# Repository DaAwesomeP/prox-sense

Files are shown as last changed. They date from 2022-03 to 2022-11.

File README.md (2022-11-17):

prox-sense
==========

[prox-sense](https://github.com/DaAwesomeP/prox-sense) is a series of printed
circuit board (PCB) designs for designed to bring robust and discreet
capacitive proximity and touch sensing to artists and makers.

**Video demonstration and poster: [Hidden Touch: Open Source Sensors for New
Interaction](https://perrynaseck.com/work/prox-sense/)**

This repository contains the KiCAD schematics, boards, and Gerber files
required to produce the sensing boards. License notice below.

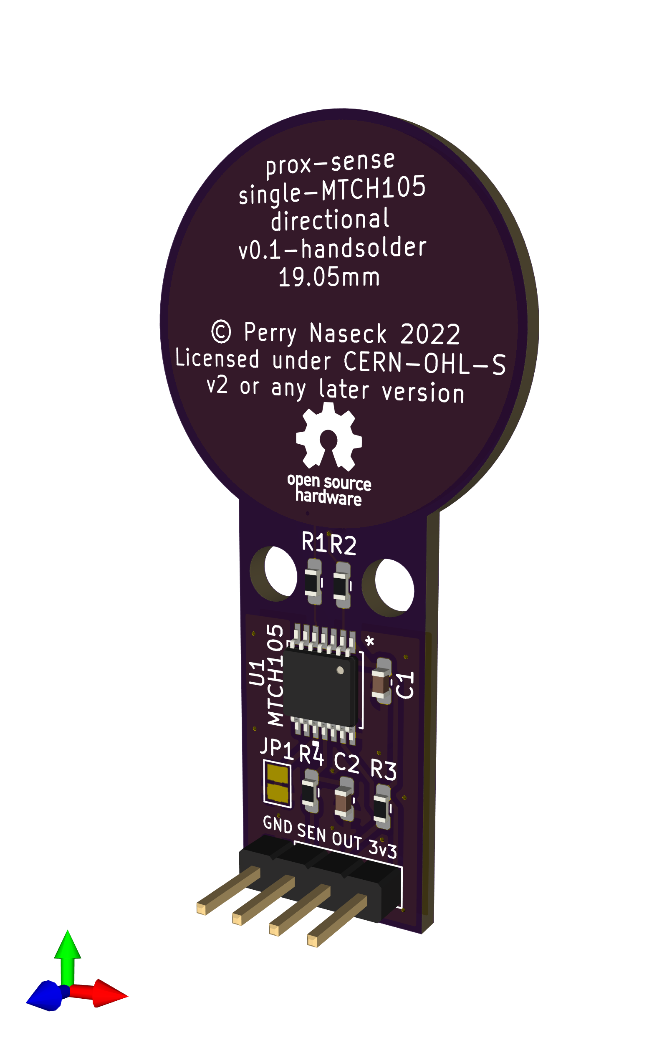
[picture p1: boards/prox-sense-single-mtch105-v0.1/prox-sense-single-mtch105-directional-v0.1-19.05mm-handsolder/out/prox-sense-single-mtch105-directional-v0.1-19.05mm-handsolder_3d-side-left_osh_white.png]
prox-sense directional board


## Premise

**Existing systems for creating interactive experiences:**

 - Expensive
 - Can be difficult to use or understand
 - Limited or nonexistent proximity detection (existing capacitive options)
 - Dense arrangements of proximity sensors may not function (existing
   capacitive options)
 - Connectivity options do not scale up to large systems of sensors
 - Equivalent/alternative optical systems are intrusive, expensive, or
   predictable (cameras, vision systems)
 - Require large amounts of processing or setup
 - Existing tactile systems are predictable (buttons, knobs, touchscreens,
   etc.)

**prox-sense promotes discoverable and new interactions:**

 - Inexpensive
 - Focus on proximity detection
 - Proximity through solid and opaque objects (sensors can be entirely hidden)
 - Directional proximity detection options allow for dense arrangements
 - Interaction is led by the objects the sensors are hidden in and the
   resulting interactions, not the sensors and sensor limitations
 - Small sensors allow for small detection areas and objects
 - Simple connectivity scales up to large systems without limiting the maximum
   number of easily-connected sensors
 - Open source and free to produce

## Boards

Currently all boards are based around the [Microchip
MTCH105](https://www.microchip.com/en-us/product/MTCH105)

 - Simple GPIO interface for detection and sensitivity adjustment. The standard
   logic output can be used directly with microcontrollers, logic circuits,
   transistors, muxes, and port expanders
 - Rejects liquids and other uncertain signal sources
 - Supports guard reference signal for solid interference mitigation
 - All boards currently use the same schematic but vary the copper/trace layout
   to achieve different detection patterns

### Directional board

 - Detects proximity and touch only directly in front of the sensors
 - Rejects rear and off-axis (side) detection using guard signal
 - Guard signal on edge allows for close-packing of sensors

### Omnidirectional board

 - Detects proximity and touch from all directions
 - Guard signal on edge allows for close-packing of sensors

## License Notice
Copyright Perry Naseck 2022.

This source describes Open Hardware and is licensed under the CERN-OHL-S v2.

You may redistribute and modify this source and make products using it under
the terms of the CERN-OHL-S v2 (https://ohwr.org/cern_ohl_s_v2.txt).

This source is distributed WITHOUT ANY EXPRESS OR IMPLIED WARRANTY,
INCLUDING OF MERCHANTABILITY, SATISFACTORY QUALITY AND FITNESS FOR A
PARTICULAR PURPOSE. Please see the CERN-OHL-S v2 for applicable conditions.

Source location: https://github.com/DaAwesomeP/prox-sense

As per CERN-OHL-S v2 section 4, should You produce hardware based on this
source, You must where practicable maintain the Source Location visible
on the external case of the prox-sense or other products you make using this
source.

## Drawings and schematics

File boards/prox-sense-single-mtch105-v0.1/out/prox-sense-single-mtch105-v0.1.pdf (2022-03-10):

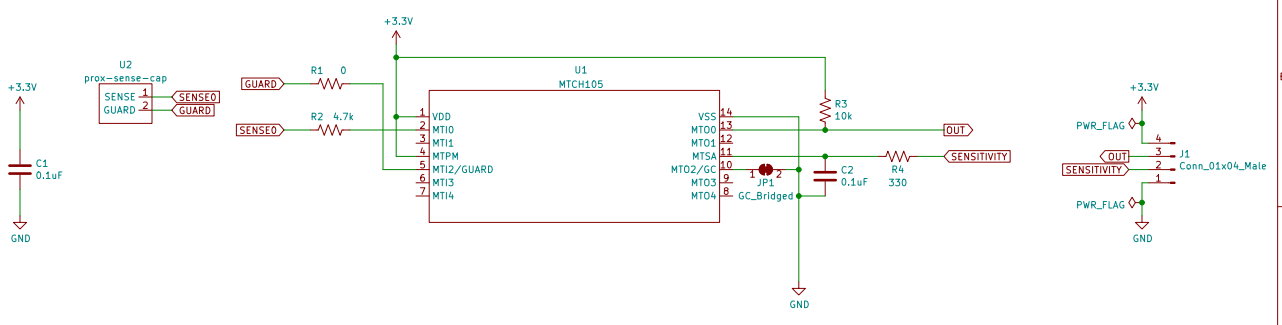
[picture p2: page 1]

Copyright Perry Naseck 2022; licensed under CERN-OHL-S v2 or any later version PWR_FLAG

MTCH105 used in place of MTCH102 due to chip shortage
This schematic used for multiple board layouts
File: prox-sense-single-mtch105-v0.1.kicad_sch Sheet: / Perry Naseck

Id: 1/1 Title: Prox Sense Single MTCH105

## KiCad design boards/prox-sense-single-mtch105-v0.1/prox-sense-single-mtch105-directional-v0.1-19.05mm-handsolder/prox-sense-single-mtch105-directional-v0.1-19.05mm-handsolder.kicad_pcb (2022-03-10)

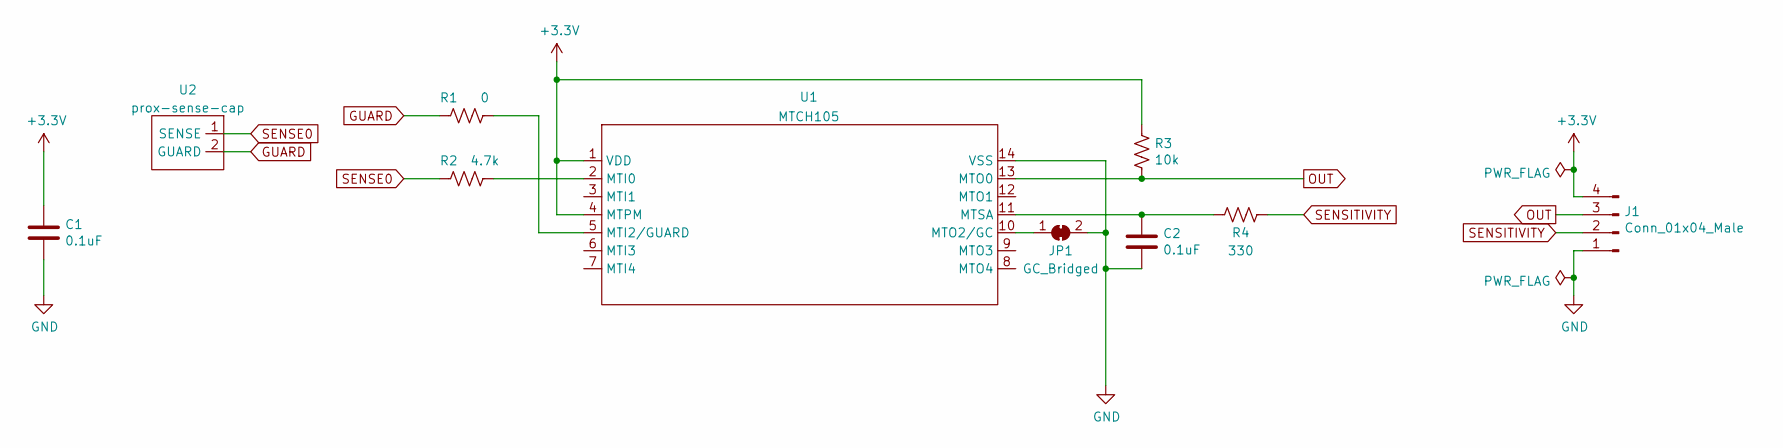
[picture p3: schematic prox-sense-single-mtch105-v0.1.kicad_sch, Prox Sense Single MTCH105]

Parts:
C1, C2: 0.1uF; C_0603_1608Metric_Pad1.08x0.95mm_HandSolder
J1: Conn_01x04_Male; PinHeader_1x04_P2.54mm_Vertical
JP1: GC_Bridged; SolderJumper-2_P1.3mm_Bridged_Pad1.0x1.5mm
R1: 0; R_0603_1608Metric_Pad0.98x0.95mm_HandSolder
R2: 4.7k; R_0603_1608Metric_Pad0.98x0.95mm_HandSolder
R3: 10k; R_0603_1608Metric_Pad0.98x0.95mm_HandSolder
R4: 330; R_0603_1608Metric_Pad0.98x0.95mm_HandSolder
U1: MTCH105; MTCH105-I&slash_ST
U2: prox-sense-cap; prox-sense-cap-omni-19.05mm

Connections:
+3V3: C1.1, J1.4, R3.1, U1.1 (VDD), U1.4 (MTPM)
GND: C1.2, C2.2, J1.1, JP1.2 (B), U1.14 (VSS)
GUARD: R1.2, U2.2 (GUARD)
unnamed: C2.1, R4.2, U1.11 (MTSA)
unnamed: JP1.1 (A), U1.10 (MTO2/GC)
unnamed: R1.1, U1.5 (MTI2/GUARD)
unnamed: R2.1, U1.2 (MTI0)
OUT: J1.3, R3.2, U1.13 (MTO0)
SENSE0: R2.2, U2.1 (SENSE)
SENSITIVITY: J1.2, R4.1

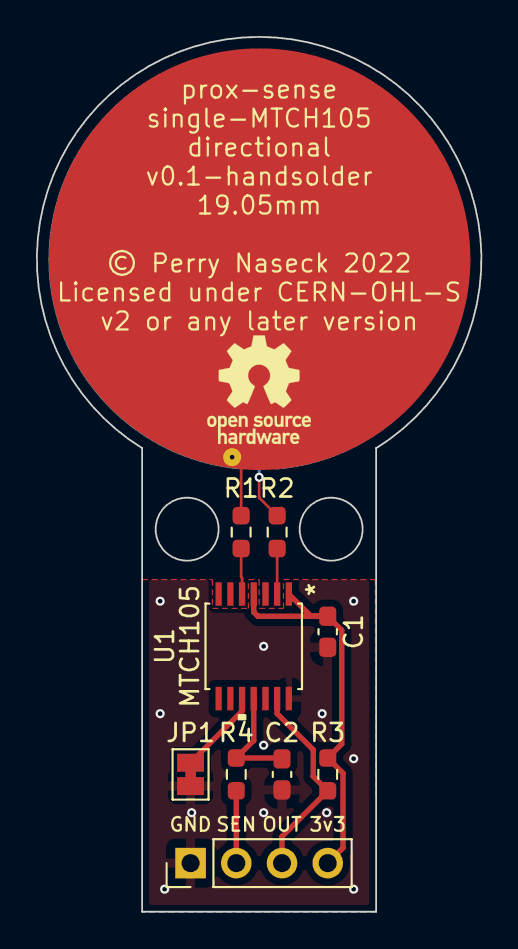
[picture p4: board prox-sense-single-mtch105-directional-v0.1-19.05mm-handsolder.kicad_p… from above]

Board: 2 copper layers, 24.7 x 48.6 mm, 10 parts (1 on the bottom side), 10 nets.

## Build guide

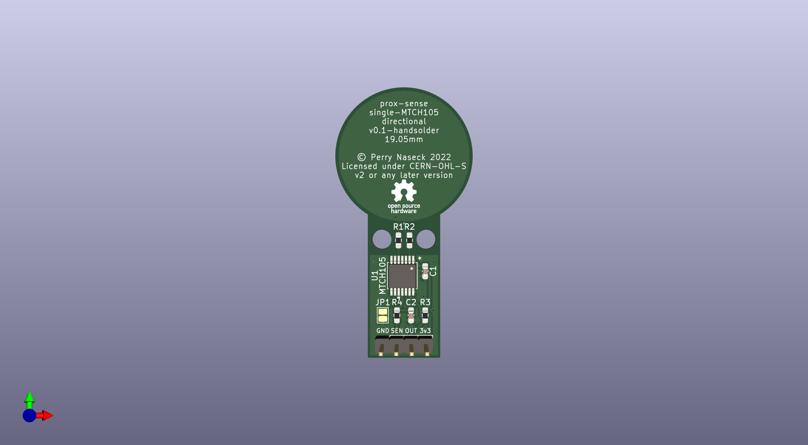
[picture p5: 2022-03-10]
boards/prox-sense-single-mtch105-v0.1/prox-sense-single-mtch105-directional-v0.1-19.05mm-handsolder/out/prox-sense-single-mtch105-directional-v0.1-19.05mm-handsolder_3d-front.png

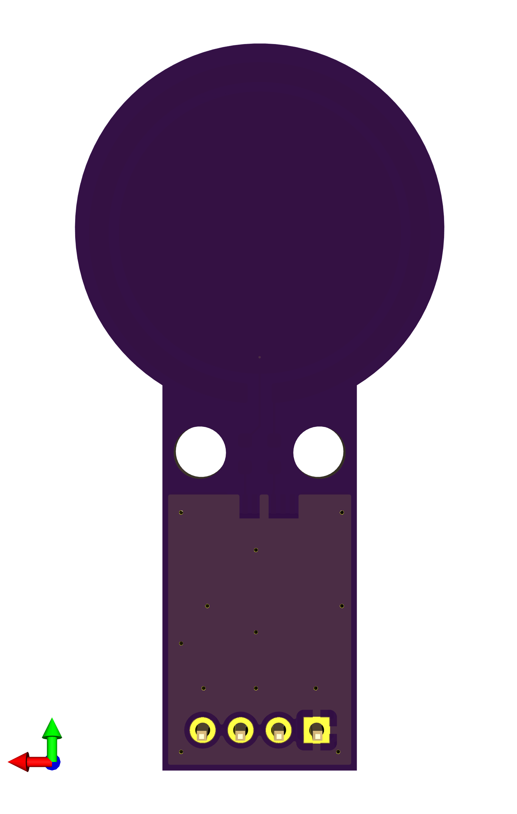
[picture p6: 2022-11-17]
boards/prox-sense-single-mtch105-v0.1/prox-sense-single-mtch105-omni-v0.1-19.05mm-handsolder/out/prox-sense-single-mtch105-omni-v0.1-19.05mm-handsolder_3d-rear_osh_white.png

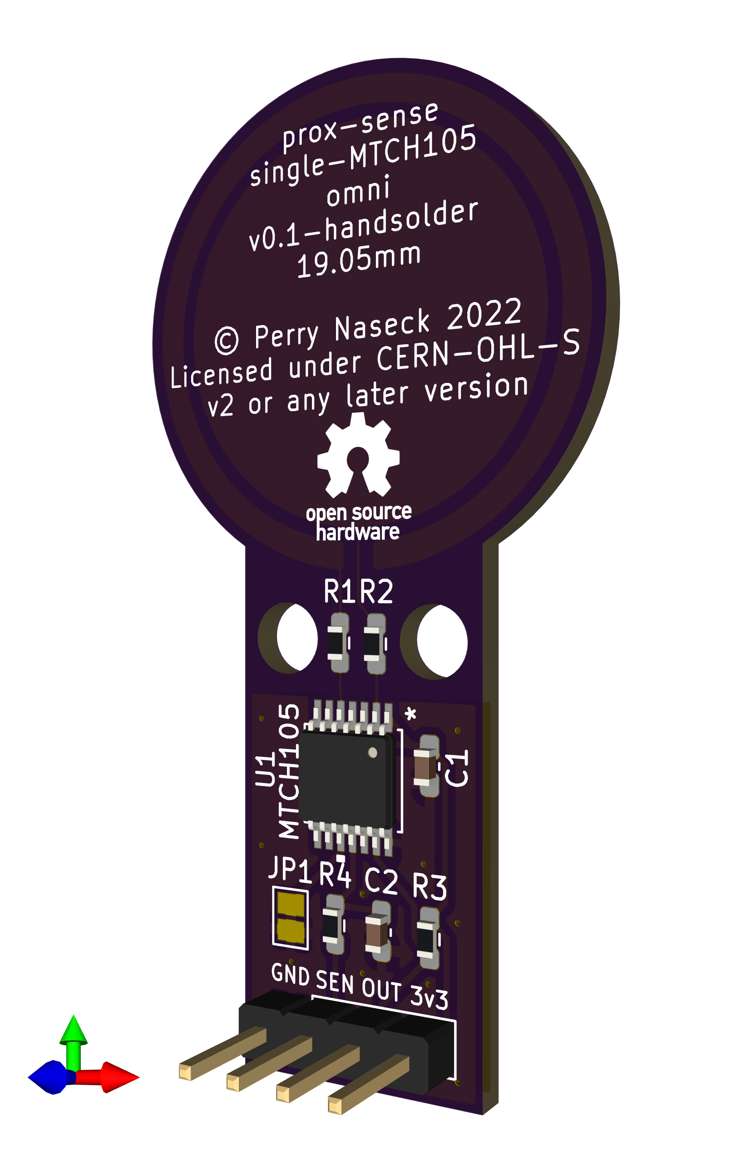
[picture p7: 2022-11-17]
boards/prox-sense-single-mtch105-v0.1/prox-sense-single-mtch105-omni-v0.1-19.05mm-handsolder/out/prox-sense-single-mtch105-omni-v0.1-19.05mm-handsolder_3d-left-angle_osh_white.png

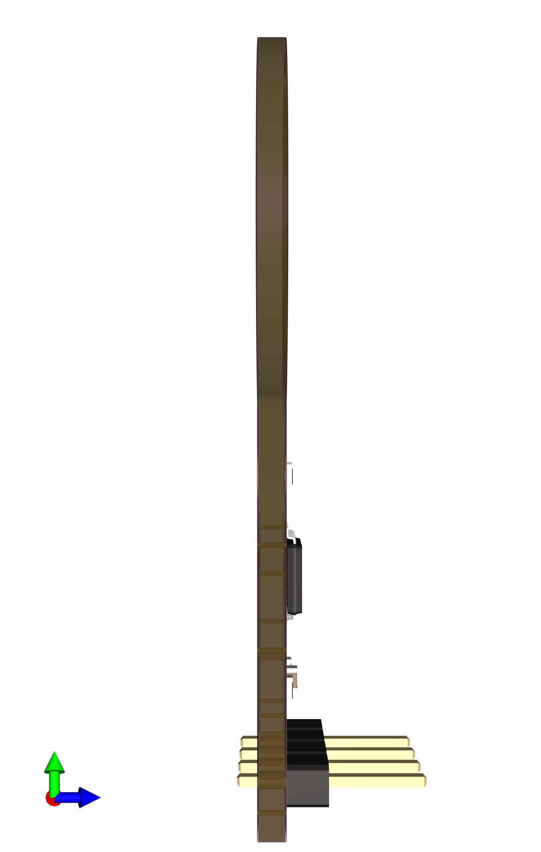
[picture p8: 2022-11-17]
boards/prox-sense-single-mtch105-v0.1/prox-sense-single-mtch105-omni-v0.1-19.05mm-handsolder/out/prox-sense-single-mtch105-omni-v0.1-19.05mm-handsolder_3d-side-left_osh_white.png

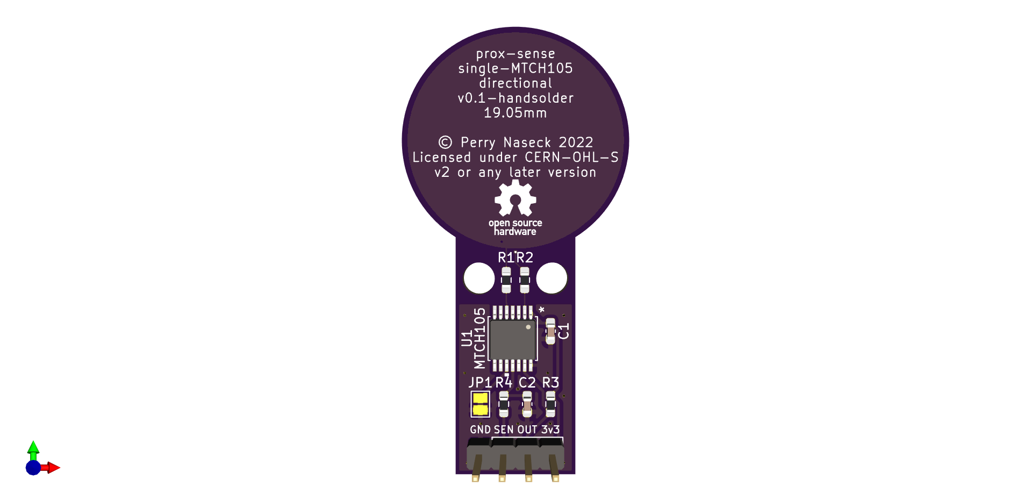
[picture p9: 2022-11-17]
boards/prox-sense-single-mtch105-v0.1/prox-sense-single-mtch105-directional-v0.1-19.05mm-handsolder/out/prox-sense-single-mtch105-directional-v0.1-19.05mm-handsolder_3d-front_osh_white.png

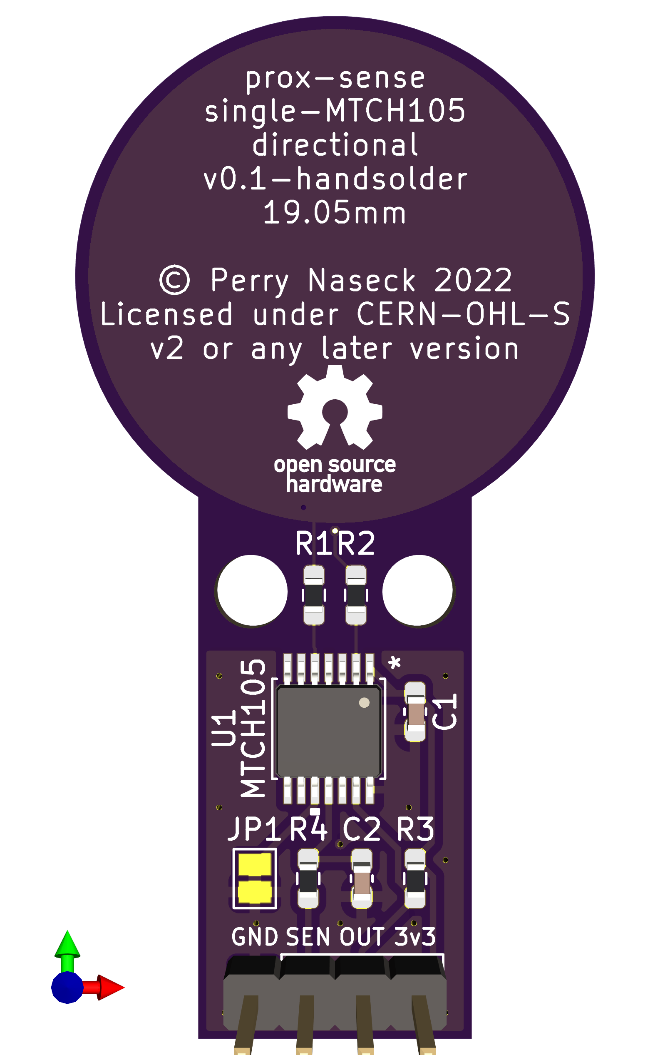
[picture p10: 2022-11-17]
boards/prox-sense-single-mtch105-v0.1/prox-sense-single-mtch105-directional-v0.1-19.05mm-handsolder/out/prox-sense-single-mtch105-directional-v0.1-19.05mm-handsolder_front_osh_white.png

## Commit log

2022-03-10 gerber zip, omni guard on one side, no vias
    [prox-sense-single-mtch105-omni-v0.1-19.05mm-handsolder-B_Cu.gbr, prox-sense-single-mtch105-omni-v0.1-19.05mm-handsolder-B_Mask.gbr, prox-sense-single-mtch105-o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]
2022-03-10 smaller directional guard via
    [prox-sense-single-mtch105-directional-v0.1-19.05mm-handsolder-B_Cu.gbr, prox-sense-single-mtch105-directional-v0.1-19.05mm-handsolder-B_Mask.gbr, prox-sense-si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]

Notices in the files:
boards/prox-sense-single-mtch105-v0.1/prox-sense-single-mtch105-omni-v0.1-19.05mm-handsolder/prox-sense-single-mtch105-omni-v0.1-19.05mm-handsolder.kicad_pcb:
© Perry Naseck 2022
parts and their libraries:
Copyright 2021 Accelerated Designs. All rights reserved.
